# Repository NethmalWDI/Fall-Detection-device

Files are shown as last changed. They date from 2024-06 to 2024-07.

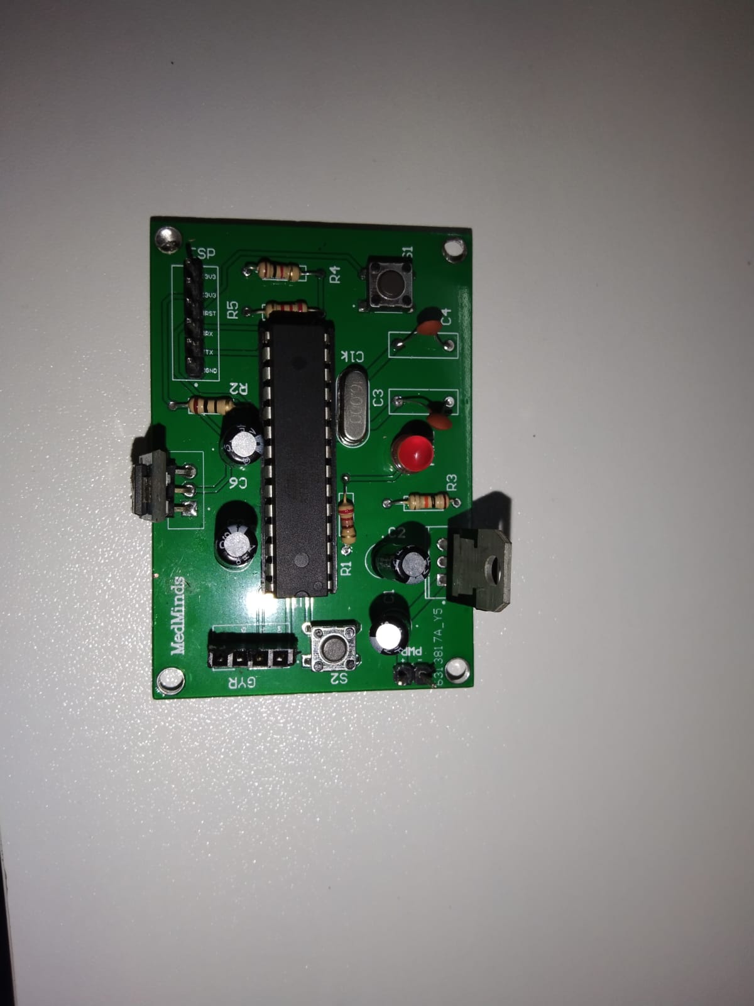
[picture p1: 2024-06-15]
Images/soldered pcb.jpg

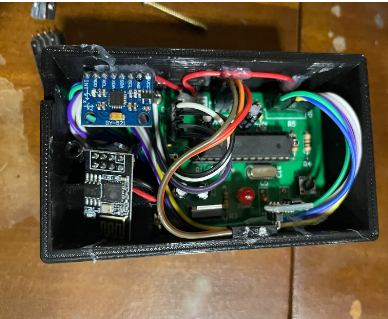
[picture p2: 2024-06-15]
Images/end assembly.png

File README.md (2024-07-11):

# Fall Detection Device

This team project was developed as part of our 2nd semester project at the University of Moratuwa. The objective of this project is to design and implement a device that detects falls in elderly people and sends a notification to a designated person via SMS.

## Project Overview

Falls are a major health risk for elderly people, and timely assistance is crucial in such situations. Our fall detection device aims to address this issue by detecting falls using a gyroscope and accelerometer, and notifying a caretaker through a WiFi-enabled communication system.

## Features

- **Fall Detection**: Utilizes the MPU6050 gyroscope and accelerometer to detect falls.
- **Notification System**: Sends an SMS to a predefined contact when a fall is detected.
- **WiFi Communication**: Uses the ESP8266 module to connect to a WiFi network and send notifications.
- **Custom PCB Design**: Designed using Altium.
- **Enclosure Design**: Modeled and simulated using SOLIDWORKS.

## Fall Detection Concepts

Our fall detection algorithm is based on analyzing movement patterns and accelerations using the MPU6050 sensor. Here are the key concepts:

- **Movement Indication**: 
  - Messages are sent to the HiveMQ server under the topic "Notifications" to indicate various movements.

- **Fall Detection**:
  - Falls are identified when the resultant acceleration drops near zero, then suddenly increases to a value higher than 1g, and finally decreases back to around 1g.

- **Walking Detection**:
  - Walking is identified when the longitudinal acceleration is about 1g, and the resultant acceleration has slightly higher values, approximately 1.1g.

- **Getting Up Detection**:
  - Getting up from the bed is detected when the longitudinal acceleration increases, and the turned angle approaches 90 degrees.

## Hardware Components

- **MPU6050**: Gyroscope and accelerometer module for motion detection.
- **ESP8266**: WiFi module for internet connectivity.
- **Custom PCB**: Designed with Altium for integrating the components.
- **Enclosure**: Designed with SOLIDWORKS to house the device.

## Team members
[Snadun Induwara](https://github.com/sandun21)  
[Imasha Nethmal](https://github.com/NethmalWDI)  
Lohan Atapattu  
Kawenndra Alwis

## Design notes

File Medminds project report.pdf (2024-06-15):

# Department of Electronic & Telecommunication Engineering University of Moratuwa

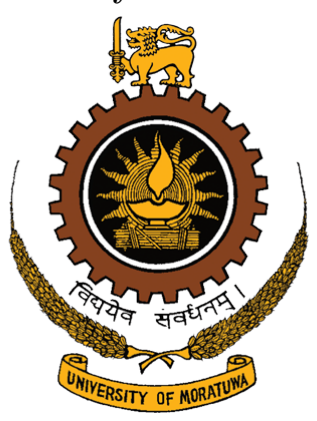
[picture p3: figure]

# BM1190 - Engineering Design Project

## Project report

# Fall Detection Device for elderly people

### Submitted by

### Alwis W.K. - 210029J Atapattu A.M.L.R. - 210054F Herath H M S I - 210218M Nethmal W D I - 210421E

### Contents

1 Introduction | 3
2 Our Device | 3
3 Technical Spesifications | 3
4 Product Architecture | 4
5 PCB Design | 5
6 Enclosure Design | 7
7 Marketing and Sales Plan | 8
8 Project so far | 9
9 Project Budget | 10
10 Task Allocation | 11
11 Areas of possible improvement | 11
12 User Manual | 12

1

### 1 Introduction

### 1.1 Problem description

In most Sri Lankan houses, adults stay alone at home during the daytime. Because of their low income, many people can’t afford a caretaker for them. There is a probability of accidents happening from sudden falls due to a lack of physical strength and mental health. And it may cause death if someone doesn’t take immediate action.
Our aim is to develop a device for these homealone adults which can send an immediate notification to a respective person if this kind of accident happens.

### 1.2 Product Idea Validation

As per our survey, over 50% of adults over the age of 60 years old had experienced a sudden fall or heart attack. And most importantly, many of them live alone in their homes. Almost all the participants wanted a solution for this matter.
And Most Importantly, There isn’t a product specifically for this purpose in the Current market.

### 2 Our Device

A fall detection device is a wearable device to stomach area. By using the given belt. To turn on the power, there is a side button and after turning it on it will automatically connect to wifi by using the esp 8266 wifi module. When the sensor identify a sudden fall it will send a message to the server using wifi, and then the server will send data to the mobile app and it will display the message that there is a fall. The device is rechargeable and can last one day.

### 3 Technical Spesifications

### 3.1 Performance in quantitative terms

Sensitivity
Based on a fall detection algorithm which identifies a fall by the sudden change of acceleration and angle

Operating time
Estimated to work 24-29 hours per one full charge. Power is provided by 3 LiPo batteries of 3.7V each in series

Dimensions
Without belt: 10 cm x 5.5 cm x 5 cm, 200g approximately

Warrenty terms
A 1 year warranty for the device will be provided with free services and replacements.

2

### 4 Product Architecture

### 4.1 Block diagram abstraction of the device

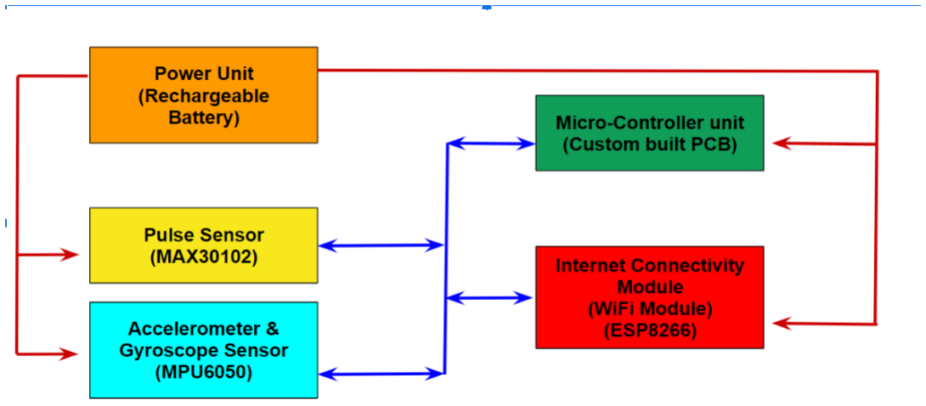
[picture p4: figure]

### 4.2 Functionality of the Blocks

Micro-Controller Unit
This is the Brain of our Product. This unit is based on an ATmega328 Microcontroller chip. We have developed a fully customized electronic circuit using the functionalities of the Microcontroller. Each and every other component are connected to this PCB via wires to transmit control, input, and output signals to and from the microcontroller

Power Unit
This unit supplies power to each and every component of the system. This unit includes LiFePO4 battery pack of 12v with a typical BMS circuit to enable charging and discharging functionalities of this unit.
Charging can be done through the power input jack, which we added to the unit and power supply to each unit will be done through wires.
Also there is an LED to indicate the SOC of the Battery pack for give a proper idea to consumers about when to charge the battery.
Charging can be done using the usual battery chargers or they can buy our custom built charger with the product as they desire.

Internet Connectivity Module
We have used the ESP 8266 module to enable the internet connectivity of the circuit to use it as an IOT device. Falls detection alerts can be sent to the server through this module.

3

Accelerometer and Gyroscope Sensor Module
This is the unit which sends signals regarding the orientation and the motion of the user to the Microcontroller unit. we have used the MPU6050 module for this purpose. we can process these signals using a microcontroller and identify whether the user has fallen or not.

### 5 PCB Design

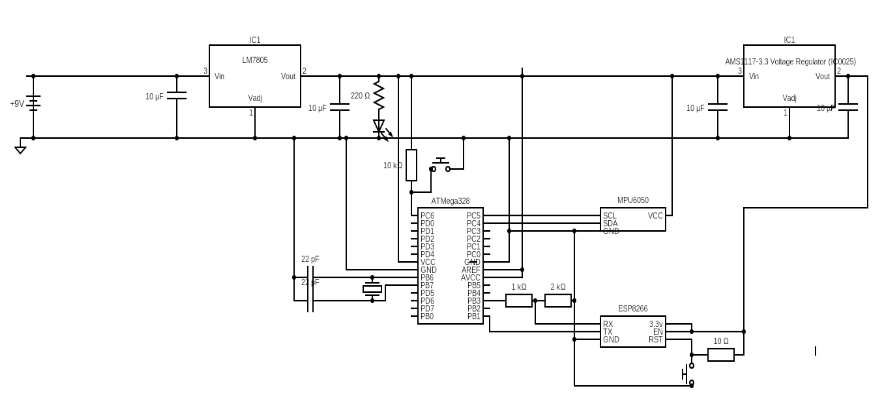
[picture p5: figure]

Schematic of the circuit

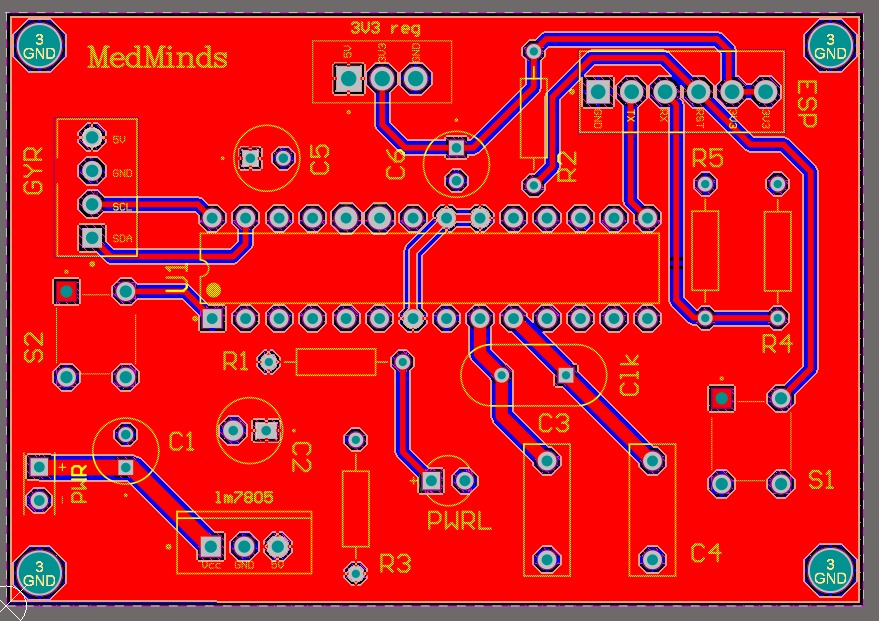
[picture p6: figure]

Top layer of the PCB

4

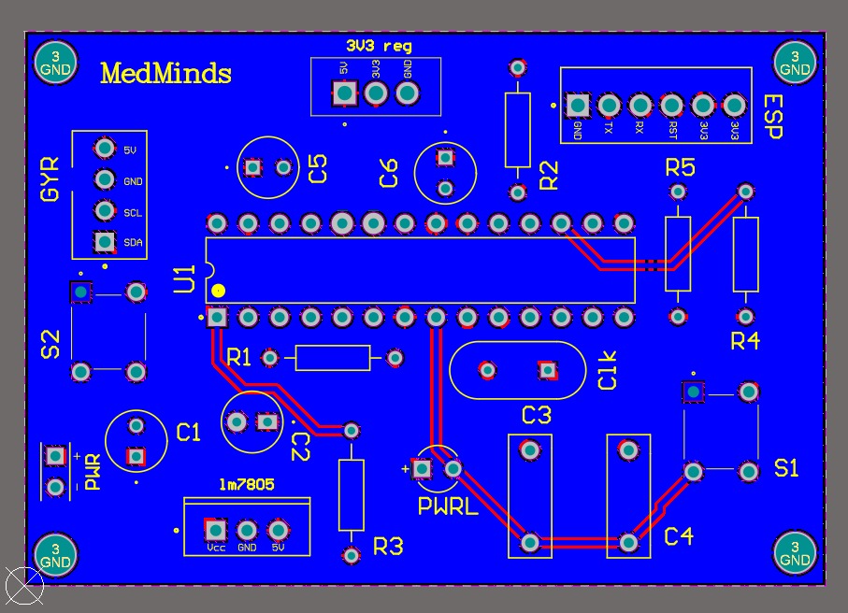
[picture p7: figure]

Bottom layer of the PCB


Soldered PCB

5

### 6 Enclosure Design

The product is a wearable device that is worn throughout the day. Therefore it is lightweight so as to not affect the daily essential tasks of elderly patients. The device should be worn on a belt or a similar article of clothing.
Considering the safety, manufacturability and user experience, the final enclosure design is as follows.

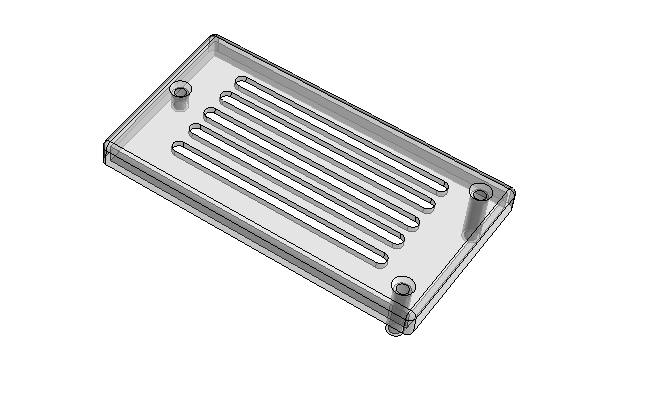
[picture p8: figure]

Upper part of the enclosure

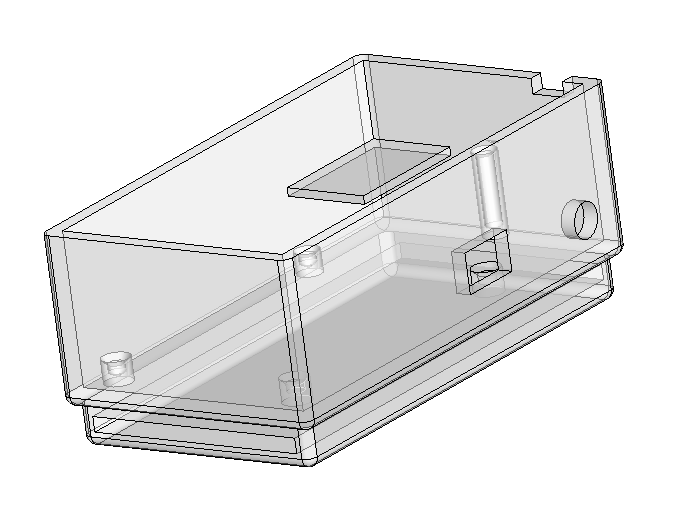
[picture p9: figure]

Lower part of the enclosure

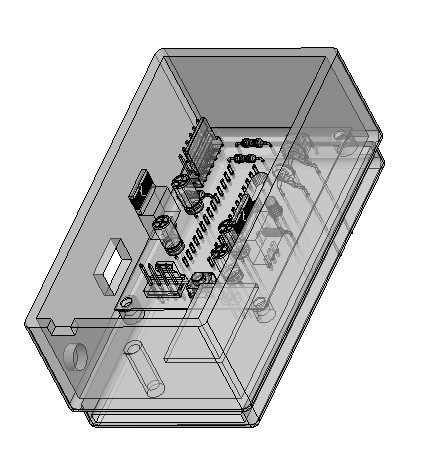
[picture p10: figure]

inside of the enclosure

6

### 7 Marketing and Sales Plan

### 7.1 Marketing and sales considerations:

As the survey we did on a local sample we found out that this is a big problem for everyone who had/has elders to care for. But we can’t find a reliable and cost-friendly solution for this not only in Sri lanka but also worldwide. So this would be a great problem to solve.And we predict that there will be a really good demand for this device not only locally but also internationally.
When marketing a device like this, it is essential to target the appropriate audience effectively. The marketing messages should be crafted to appeal to the elderly and their caregivers, highlighting the benefits of using the device, such as increased safety and peace of mind. The messaging should focus on how the device works and about the easy-to-use features.
Additionally, the marketing strategy should include targeting healthcare professionals, such as physicians and nurses, who can recommend the device to users. Social media platforms can also be used to target the elderly and their caregivers effectively.
We can use digital marketing strategies like paid video promotions(product reviews),google and social media ads campaigns(display,search,...etc). Also we can use our own Ecommerce website and other reputed multi vendorOnline shopping platforms to sell the product globally.

### 7.2 After-Sale Service Considerations:

Providing excellent customer service is crucial in maintaining a positive reputation and ensuring customer satisfaction. The after-sale service should include technical support and troubleshooting for the device, as well as easy-to-access customer support options, such as phone or email.Also that more than 99% uptime of the real time monitoring server is very essential. Providing educational materials and user guides can also be helpful in ensuring customers understand how to use the device properly.Also we can maintain a webpage as a forum,so the customers can share their ideas and problems with others and we can actively involve them to further development of the product. Additionally, offering device maintenance services, such as battery replacement or driver/software updates, can help extend the device’s lifespan and improve customer satisfaction. Regular follow-ups to check in on customer satisfaction and offer additional support can also enhance the after-sale experience.

7

### 8 Project so far

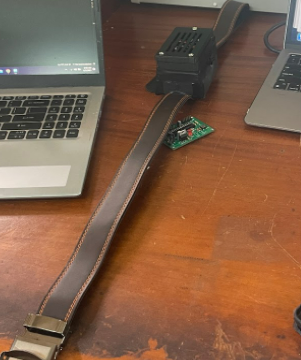
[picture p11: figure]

8

### 9 Project Budget

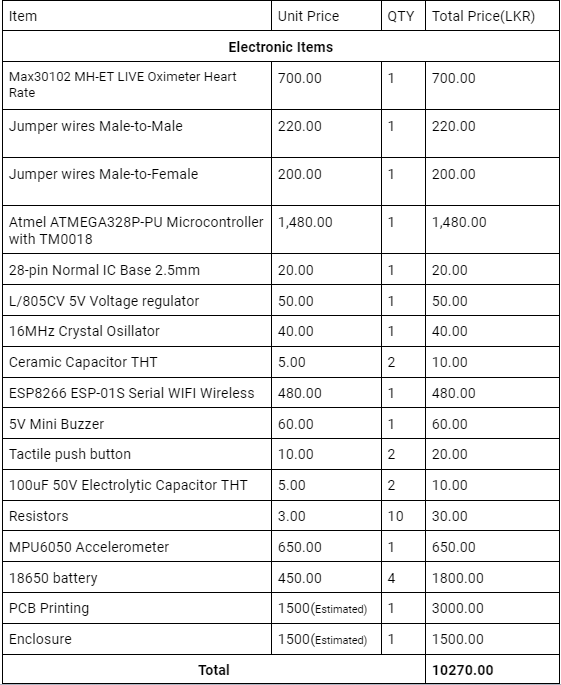
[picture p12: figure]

9

### 10 Task Allocation

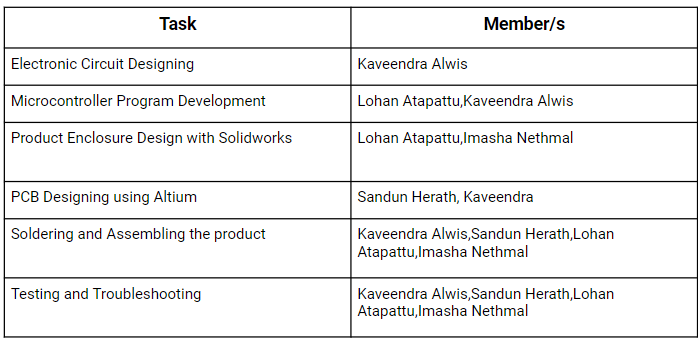
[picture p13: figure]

### 11 Areas of possible improvement

- Most suitable as a necklace or a watch hence plan to build more compact device using SMD electronic components for that purpose
- More suitable database support, APP development for the device,SMS and Email Enabled Notification
- More improvements to the algorithm using machine learning concepts to get much-optimized output.
- With use of smaller batteries, the enclosure can be further miniaturized.The size and weight of the device could be reduced to make the ability to wear and engage in daily tasks easier

10

### 12 User Manual

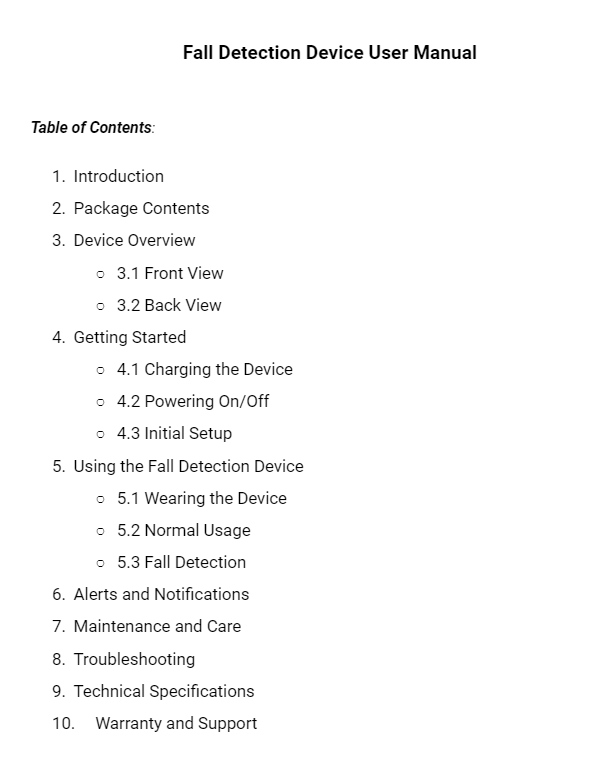
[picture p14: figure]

11

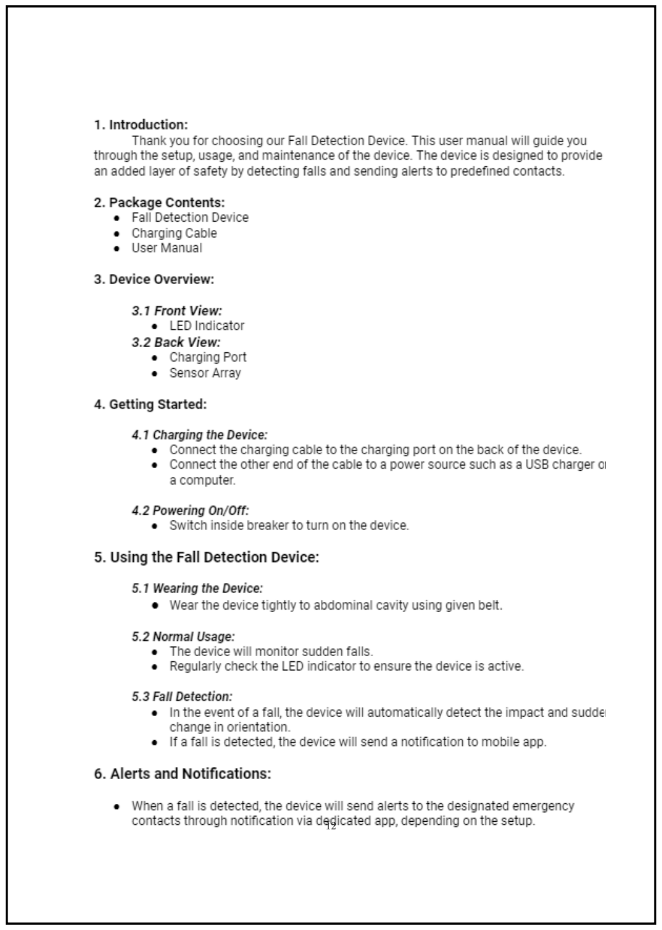
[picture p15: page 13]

12

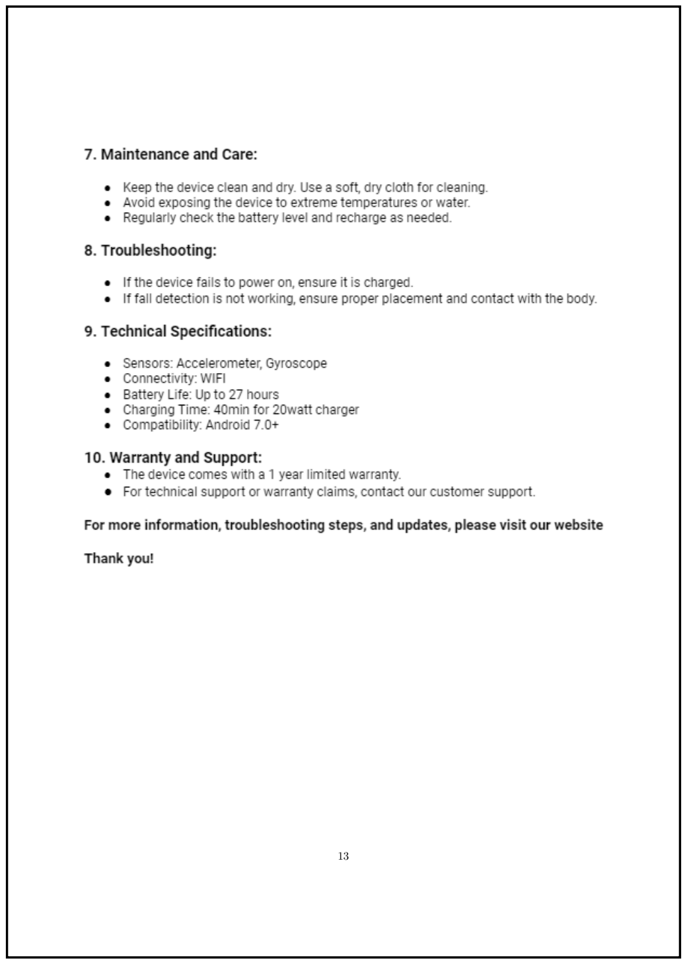
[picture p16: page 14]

13

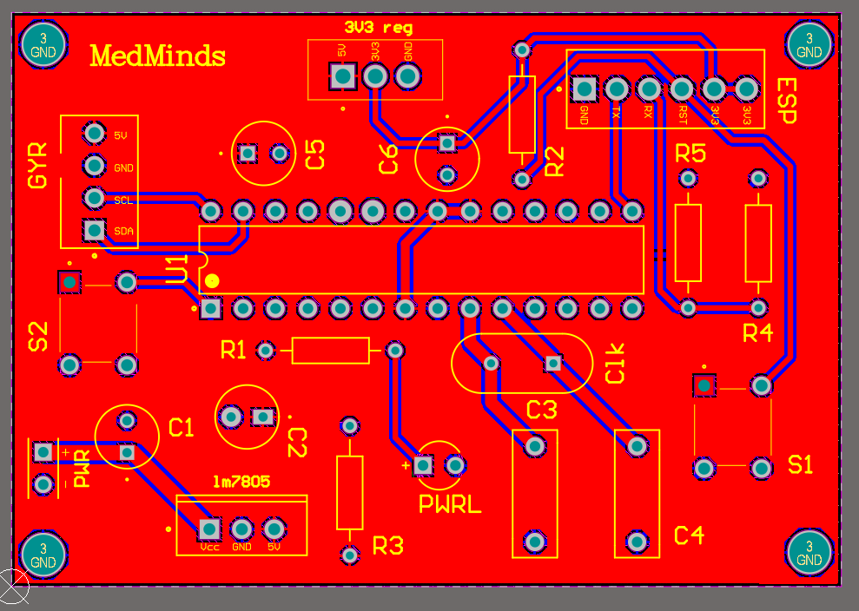
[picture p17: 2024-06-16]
PCB design/images/top_layer.png

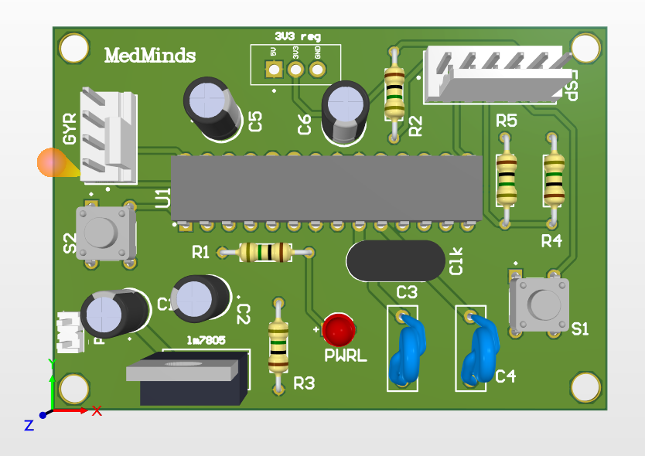
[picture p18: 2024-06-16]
PCB design/images/3d.png

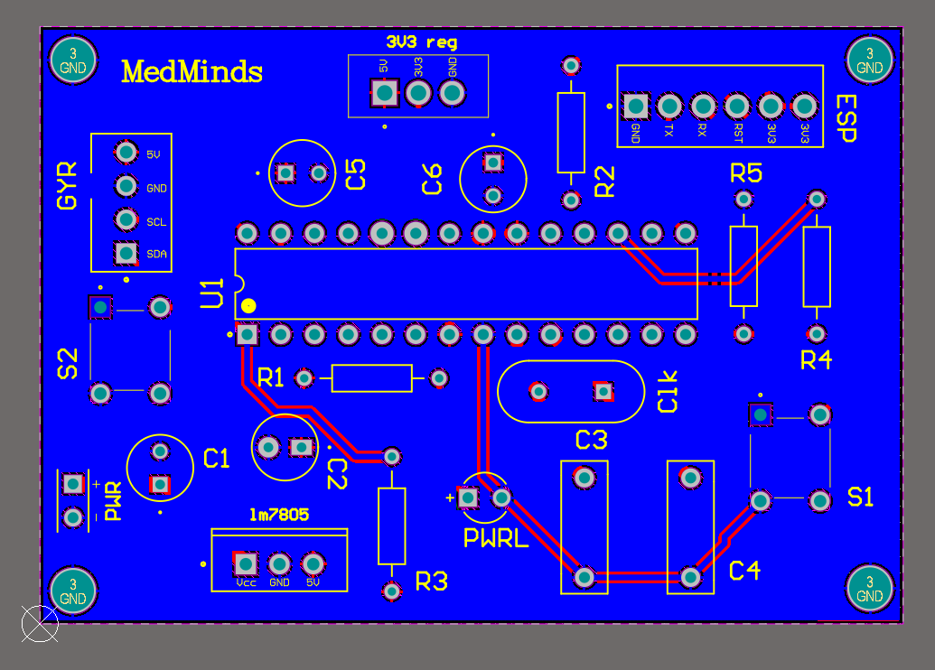
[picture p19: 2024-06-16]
PCB design/images/bottom_layer.png

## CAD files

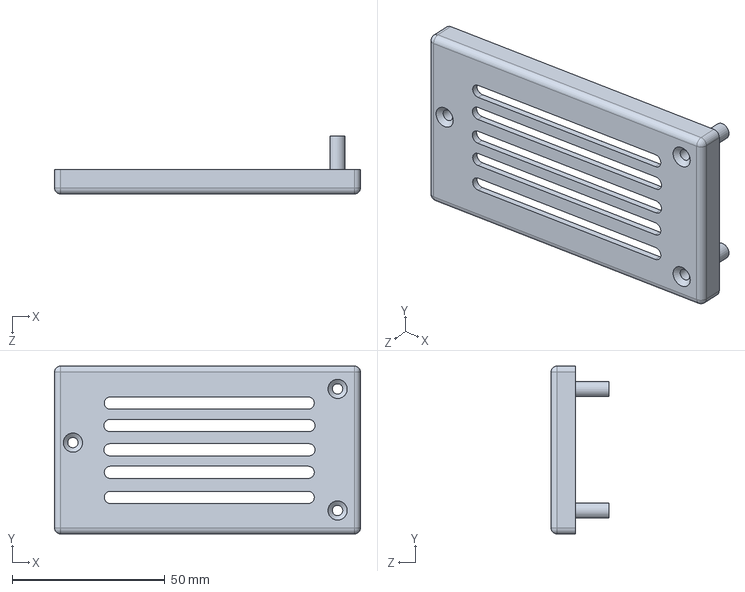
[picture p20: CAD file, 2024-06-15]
Enclosure/lid.SLDPRT
100.2 x 55.0 x 19.0 mm

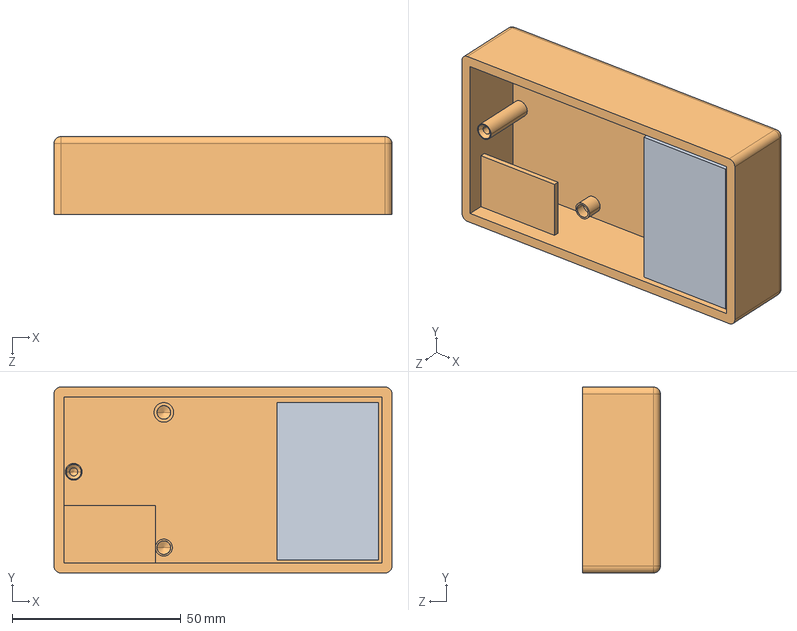
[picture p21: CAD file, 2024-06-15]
Enclosure/bottom.STEP
100.0 x 55.0 x 23.0 mm

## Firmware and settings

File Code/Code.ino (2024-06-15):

#include <Wire.h>
const int MPU = 0x68; // MPU6050 I2C address
float AccX, AccY, AccZ;
int Araw1,Araw2;
float GyroX, GyroY, GyroZ;
float accAngleX, accAngleY, gyroAngleX, gyroAngleY, gyroAngleZ;
float roll, pitch, yaw;
float AccErrorX, AccErrorY, GyroErrorX, GyroErrorY, GyroErrorZ;
float elapsedTime, currentTime, previousTime;
int c = 0;
boolean fall = false; //stores if a fall has occurred
boolean trigger1 = false; //stores if first trigger (lower threshold) has occurred
boolean trigger2 = false; //stores if second trigger (upper threshold) has occurred
boolean trigger3 = false; //stores if third trigger (orientation change) has occurred
byte trigger1count = 0; //stores the counts past since trigger 1 was set true
byte trigger2count = 0; //stores the counts past since trigger 2 was set true
byte trigger3count = 0; //stores the counts past since trigger 3 was set true
int angleChange = 0;
void setup() {
  Serial.begin(19200);
  Wire.begin();                      // Initialize comunication
  Wire.beginTransmission(MPU);       // Start communication with MPU6050 // MPU=0x68
  Wire.write(0x6B);                  // Talk to the register 6B
  Wire.write(0x00);                  // Make reset - place a 0 into the 6B register
  Wire.endTransmission(true);        //end the transmission

  // Configure Accelerometer Sensitivity - Full Scale Range (default +/- 2g)
  Wire.beginTransmission(MPU);
  Wire.write(0x1C);                  //Talk to the ACCEL_CONFIG register (1C hex)
  Wire.write(0x10);                  //Set the register bits as 00010000 (+/- 8g full scale range)
  Wire.endTransmission(true);
  // Configure Gyro Sensitivity - Full Scale Range (default +/- 250deg/s)
  Wire.beginTransmission(MPU);
  Wire.write(0x1B);                   // Talk to the GYRO_CONFIG register (1B hex)
  Wire.write(0x10);                   // Set the register bits as 00010000 (1000deg/s full scale)
  Wire.endTransmission(true);
  delay(20);

  // Call this function if you need to get the IMU error values for your module
  calculate_IMU_error();
  delay(20);
}

void loop() {
  // === Read acceleromter data === //
  Wire.beginTransmission(MPU);
  Wire.write(0x3B); // Start with register 0x3B (ACCEL_XOUT_H)
  Wire.endTransmission(false);
  Wire.requestFrom(MPU, 6, true); // Read 6 registers total, each axis value is stored in 2 registers
  //For a range of +-2g, we need to divide the raw values by 16384, according to the datasheet
  AccX = (Wire.read() << 8 | Wire.read()) / 4096.0;
  AccY = (Wire.read() << 8 | Wire.read()) / 4096.0; // Y-axis value
  AccZ = (Wire.read() << 8 | Wire.read()) / 4096.0; // Z-axis value
 
  accAngleX = (atan(AccY / sqrt(pow(AccX, 2) + pow(AccZ, 2))) * 180 / PI) - 0.58; // AccErrorX ~(0.58) See the calculate_IMU_error()custom function for more details
  accAngleY = (atan(-1 * AccX / sqrt(pow(AccY, 2) + pow(AccZ, 2))) * 180 / PI) + 1.58; // AccErrorY ~(-1.58)
     
  float ACC = pow(pow(AccX, 2) + pow(AccY, 2) + pow(AccZ, 2), 0.5);   // calculating Amplitute vactor for 3 axis

  
  previousTime = currentTime;        // Previous time is stored before the actual time read
  currentTime = millis();            // Current time actual time read
  elapsedTime = (currentTime - previousTime)/ 1000; // Divide by 1000 to get seconds
  Wire.beginTransmission(MPU);
  Wire.write(0x43); // Gyro data first register address 0x43
  Wire.endTransmission(false);
  Wire.requestFrom(MPU, 6, true); 
  GyroX = (Wire.read() << 8 | Wire.read()) / 32.8;
  GyroY = (Wire.read() << 8 | Wire.read()) / 32.8;
  GyroZ = (Wire.read() << 8 | Wire.read()) / 32.8;

  // Correct the outputs with the calculated error values
  GyroX = GyroX + 0.56; // GyroErrorX ~(-0.56)
  GyroY = GyroY - 2; // GyroErrorY ~(2)
  GyroZ = GyroZ + 0.79; // GyroErrorZ ~ (-0.8)


  // Currently the raw values are in degrees per seconds, deg/s, so we need to multiply by sendonds (s) to get the angle in degrees
  gyroAngleX = (GyroX * elapsedTime) + gyroAngleX; // deg/s * s = deg
  gyroAngleY = (GyroY * elapsedTime) + gyroAngleY;
  gyroAngleZ = (GyroZ * elapsedTime) + gyroAngleZ;
  // Print the values on the serial monitor
  Serial.print(AccX);
  Serial.print('/');
  Serial.print(AccY);
  Serial.print('/');
  Serial.print(AccZ);
  Serial.print('/');
  Serial.println(ACC);
 
  
  if (ACC <= 1 && trigger2 == false) { //if AM breaks lower threshold (0.4g)     
  trigger1 = true;     
  Serial.println("TRIGGER 1 ACTIVATED");   
  }   
  if (trigger1 == true) {     
  trigger1count++;     
  if (ACC >= 1.5) { //if AM breaks upper threshold (3g)
        trigger2 = true;
        Serial.println("TRIGGER 2 ACTIVATED");
        trigger1 = false; trigger1count = 0;
      }
    }
    if (trigger2 == true) {
      trigger2count++;
      angleChange = pow(pow(GyroX, 2) + pow(GyroY, 2) + pow(GyroZ, 2), 0.5); 
      Serial.println(angleChange);
      if (angleChange >= 20 && angleChange <= 400) { //if orientation changes by between 80-100 degrees       
  trigger3 = true; trigger2 = false; trigger2count = 0;       
  Serial.println(angleChange);       
  Serial.println("TRIGGER 3 ACTIVATED");     
  }   
  }   
  if (trigger3 == true) {     
  trigger3count++;     
  if (trigger3count >= 5) {
        angleChange = pow(pow(GyroX, 2) + pow(GyroY, 2) + pow(GyroZ, 2), 0.5);
        delay(10);
        Serial.println(angleChange);
        if ((angleChange >= 0) && (angleChange <= 10)) { //if orientation changes remains between 0-10 degrees         
  fall = true; trigger3 = false; trigger3count = 0;         
  Serial.println(angleChange);       }       
  else { //user regained normal orientation         
  trigger3 = false; trigger3count = 0;         
  Serial.println("TRIGGER 3 DEACTIVATED");       
  }     
  }   
  }   
  if (fall == true) { //in event of a fall detection     
  Serial.println("FALL DETECTED");    //IOT Code goes here       
  fall = false;   
  }   
  if (trigger2count >= 6) { //allow 0.5s for orientation change
      trigger2 = false; trigger2count = 0;
      Serial.println("TRIGGER 2 DECACTIVATED");
    }
    if (trigger1count >= 6) { //allow 0.5s for AM to break upper threshold
      trigger1 = false; trigger1count = 0;
      Serial.println("TRIGGER 1 DECACTIVATED");
    }
    delay(100);
  }
  


void calculate_IMU_error() {
  // We can call this funtion in the setup section to calculate the accelerometer and gyro data error. From here we will get the error values used in the above equations printed on the Serial Monitor.
  // Note that we should place the IMU flat in order to get the proper values, so that we then can the correct values
  // Read accelerometer values 200 times
  while (c < 200) {
    Wire.beginTransmission(MPU);
    Wire.write(0x3B);
    Wire.endTransmission(false);
    Wire.requestFrom(MPU, 6, true);
    AccX = (Wire.read() << 8 | Wire.read()) / 4096.0 ;
    AccY = (Wire.read() << 8 | Wire.read()) / 4096.0 ;
    AccZ = (Wire.read() << 8 | Wire.read()) / 4096.0 ;
    // Sum all readings
    AccErrorX = AccErrorX + ((atan((AccY) / sqrt(pow((AccX), 2) + pow((AccZ), 2))) * 180 / PI));
    AccErrorY = AccErrorY + ((atan(-1 * (AccX) / sqrt(pow((AccY), 2) + pow((AccZ), 2))) * 180 / PI));
    c++;
  }
  //Divide the sum by 200 to get the error value
  AccErrorX = AccErrorX / 200;
  AccErrorY = AccErrorY / 200;
  c = 0;
  // Read gyro values 200 times
  while (c < 200) {
    Wire.beginTransmission(MPU);
    Wire.write(0x43);
    Wire.endTransmission(false);
    Wire.requestFrom(MPU, 6, true);
    GyroX = Wire.read() << 8 | Wire.read();
    GyroY = Wire.read() << 8 | Wire.read();
    GyroZ = Wire.read() << 8 | Wire.read();
    // Sum all readings
    GyroErrorX = GyroErrorX + (GyroX / 131.0);
    GyroErrorY = GyroErrorY + (GyroY / 131.0);
    GyroErrorZ = GyroErrorZ + (GyroZ / 131.0);
    c++;
  }
  //Divide the sum by 200 to get the error value
  GyroErrorX = GyroErrorX / 200;
  GyroErrorY = GyroErrorY / 200;
  GyroErrorZ = GyroErrorZ / 200;
  // Print the error values on the Serial Monitor
  Serial.print("AccErrorX: ");
  Serial.println(AccErrorX);
  Serial.print("AccErrorY: ");
  Serial.println(AccErrorY);
  Serial.print("GyroErrorX: ");
  Serial.println(GyroErrorX);
  Serial.print("GyroErrorY: ");
  Serial.println(GyroErrorY);
  Serial.print("GyroErrorZ: ");
  Serial.println(GyroErrorZ);
}
